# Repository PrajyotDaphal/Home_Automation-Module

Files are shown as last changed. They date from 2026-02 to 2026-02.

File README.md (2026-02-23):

# 🏠 Home Automation Control Module (PCB Based)

## 📌 Project Overview

This project is a **PCB-based Home Automation Control Module** designed to control multiple AC appliances safely using relay isolation. The system uses optocouplers for electrical isolation, transistor drivers for relay switching, and an onboard AC-to-DC power module to power the control circuit.

The module can be controlled using:

* Microcontroller (ESP8266, Arduino, etc.)
* External digital logic
* Smartphone-based IoT system
* Manual control system

This design ensures **safety, reliability, and industrial-level performance**.

---

## ✨ Features

* Control up to **8 AC appliances**
* **Complete electrical isolation** using PC817 optocouplers
* **Onboard AC-DC converter (HLK-10M05)** – no external power supply required
* **Relay driver circuit using BC547 transistors**
* **Flyback diode protection** for relays
* **Status LEDs for each channel**
* **RC snubber for noise protection**
* **Compact and optimized PCB layout**
* Suitable for:

  * Home automation
  * Industrial automation
  * IoT systems
  * Smart switchboards

---

## 🔧 Hardware Components

| Component | Quantity |
| --- | --- |
| HLK-10M05 AC-DC Module | 1 |
| Relay (5V) | 8 |
| PC817 Optocoupler | 8 |
| BC547 Transistor | 8 |
| 1N4007 Diode | 8+ |
| LEDs | 8 |
| Resistors (330Ω, 1kΩ, 220kΩ, etc.) | Multiple |
| Capacitors (Electrolytic and Ceramic) | Multiple |
| Screw Terminals | Multiple |
| Buzzer | 1 |
| MOV (optional safety) | 1 |

---

## ⚡ Power Supply

**Input:**

* 230V AC mains

**Output:**

* 5V DC (from HLK-10M05)

Used to power:

* Optocouplers
* Relay coils
* Logic circuit

---

## 🔌 Pin Configuration

### Input Control Header

| Pin | Function |
| --- | --- |
| IN1 | Relay 1 control |
| IN2 | Relay 2 control |
| IN3 | Relay 3 control |
| IN4 | Relay 4 control |
| IN5 | Relay 5 control |
| IN6 | Relay 6 control |
| IN7 | Relay 7 control |
| IN8 | Relay 8 control |
| VCC | 5V |
| GND | Ground |

---

## 🔄 Working Principle

1. Control signal applied to input pin
2. Optocoupler provides isolation
3. Transistor amplifies signal
4. Relay activates
5. Appliance turns ON/OFF

Isolation ensures protection from high voltage.

---

## 📷 Schematic

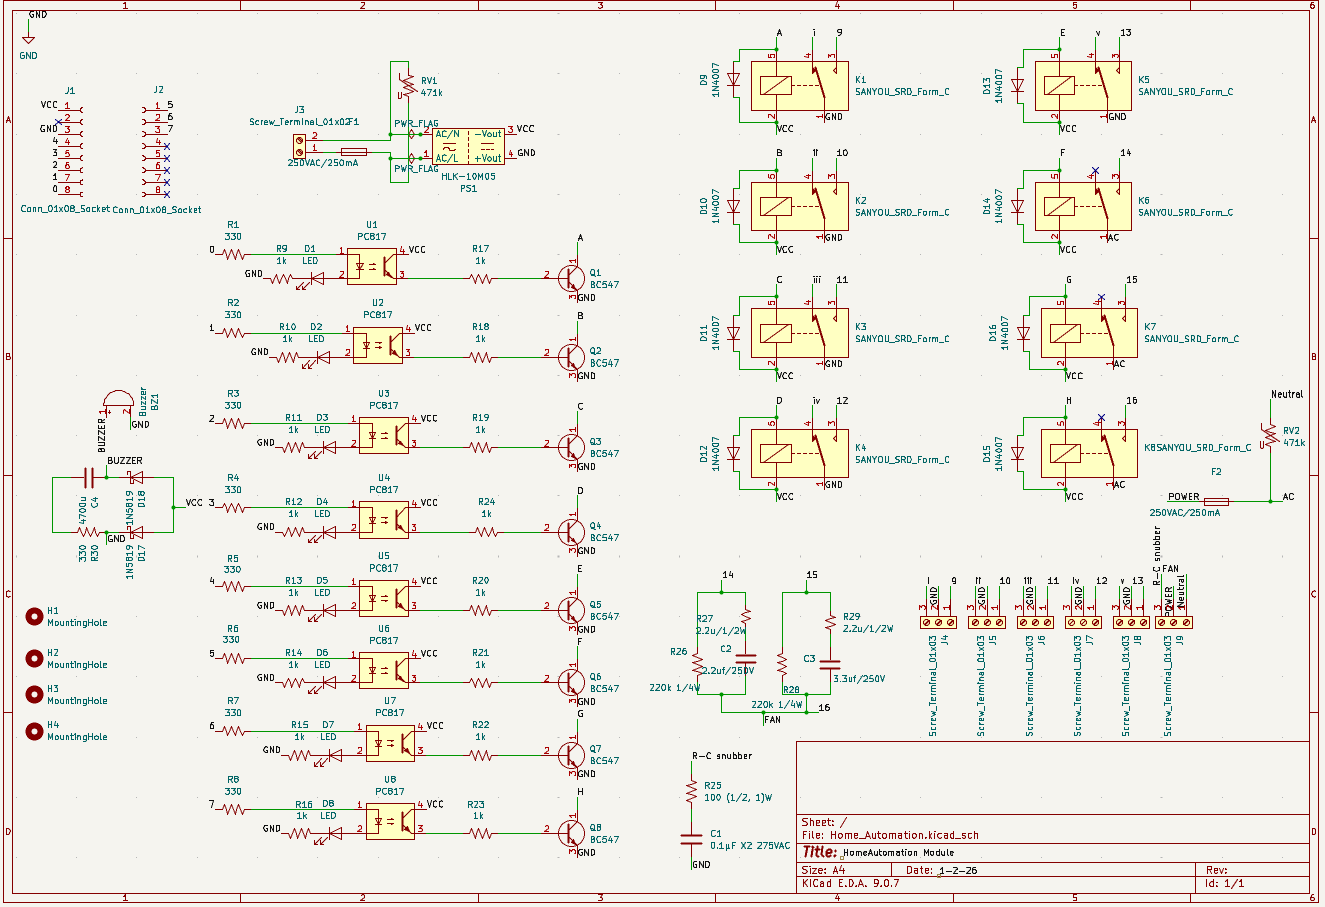
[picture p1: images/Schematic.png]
Schematic


---

## 🧩| Full Layout | Upper Copper |

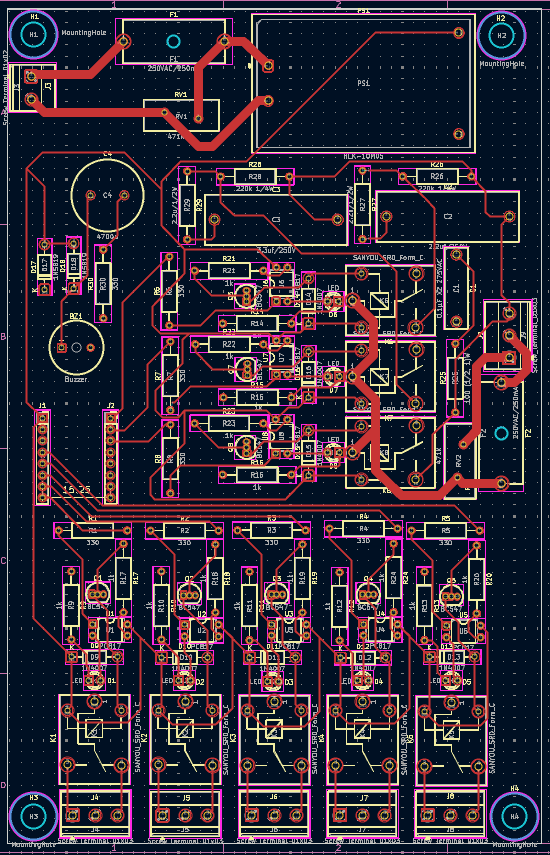
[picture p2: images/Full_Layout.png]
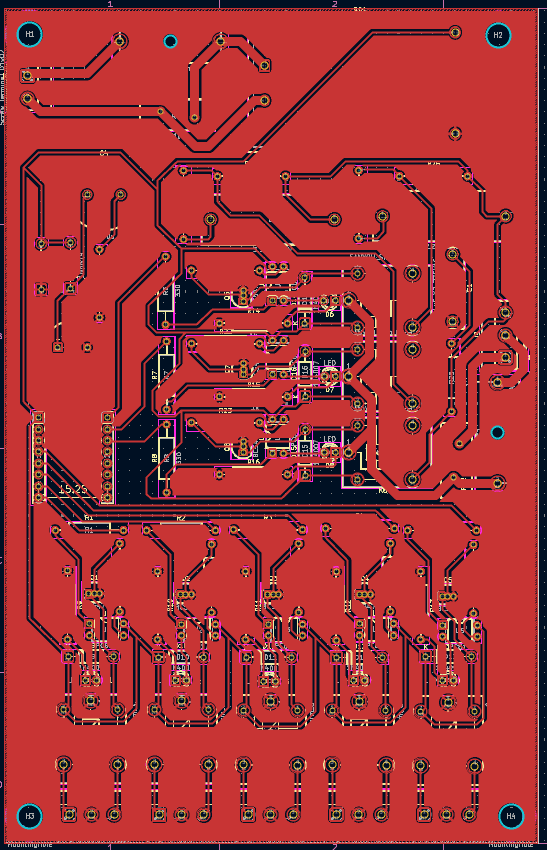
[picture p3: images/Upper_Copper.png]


---

## 🔷 PCB 3D View

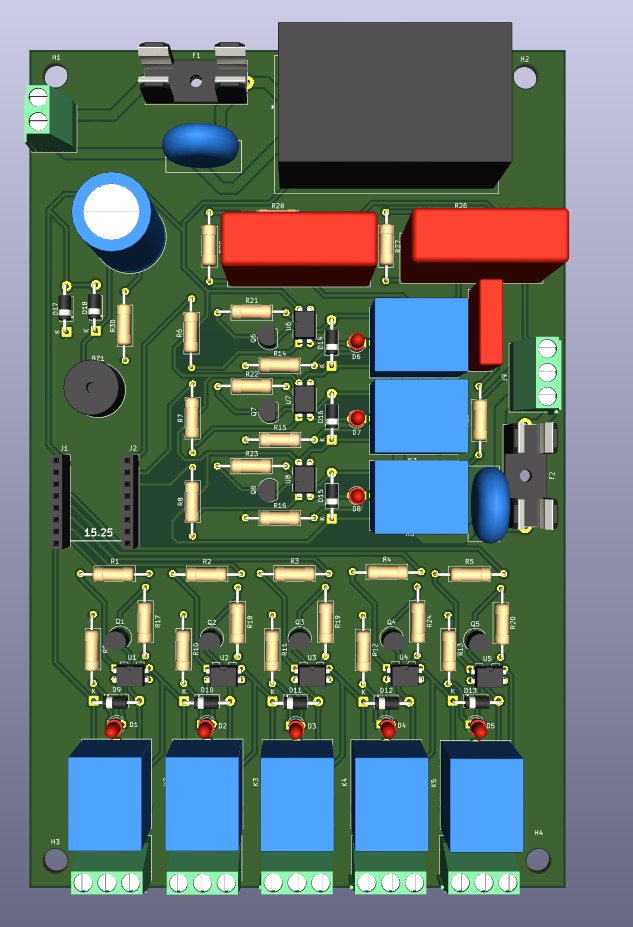
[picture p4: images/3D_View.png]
3D_View


---

## 🛡️ Safety Features

* Optocoupler isolation
* Flyback diode protection
* RC snubber protection
* Proper PCB trace width for AC
* Separate AC and DC sections
* Fuse protection support

---

## 🌐 Applications

* Smart Home Automation
* IoT Control Systems
* Industrial Automation
* Remote Appliance Control
* Smart Switchboard

---

## 🧠 Compatible Controllers

* ESP8266
* ESP32
* Arduino Uno / Nano
* Raspberry Pi
* Any microcontroller with GPIO output

---

## 📁 Project Structure

```
Home-Automation-PCB/
│
├── KiCAD/
│   └── home_automation.kicad_pcb
│   └── home_automation.kicad_sch
│   └── home_automation.kicad_prl
│   └── home_automation.kicad_pro
│   └── home_automation.dsn
│ 
├── images/
│   ├── schematic.png
│   └── pcb_layout.png
|   └── 3D_View.png
|   └── Upper_Copper.png
│
├── gerber/
│   └── production files
|
├── gerber/Drill
│   └── production files
│
└── README.md
```

---

## 🚀 How to Use

1. Connect AC mains input
2. Connect appliances to relay terminals
3. Connect microcontroller to input header
4. Apply control signal
5. Appliance will turn ON/OFF

---

## ⚠️ Warning

This project uses **HIGH VOLTAGE AC**.

* Do not touch while powered
* Use proper insulation
* Use fuse and enclosure
* Only trained persons should handle

---

## 📌 Author

**Project by:** Prajyot Daphal
**Designed using:** KiCad
**Type:** Home Automation PCB Module

---

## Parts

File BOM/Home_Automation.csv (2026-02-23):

Id | Designator | Footprint | Quantity | Designation | Supplier and ref
1 | D2,D3,D7,D4,D8,D1,D6,D5 | LED_D3.0mm | 8 | LED
2 | U5,U3,U2,U6,U7,U8,U1,U4 | DIP-4_W7.62mm | 8 | PC817
3 | J5,J7,J8,J4,J9,J6 | TerminalBlock_Phoenix_MKDS-1,5-3_1x03_P5.00mm_Horizontal | 6 | Screw_Terminal_01x03
4 | D16,D9,D15,D11,D12,D13,D10,D14 | D_DO-41_SOD81_P10.16mm_Horizontal | 8 | 1N4007
5 | R15,R18,R20,R24,R13,R21,R23,R16,R22,R9,R17,R19,R14,R10,R11,R12 | R_Axial_DIN0309_L9.0mm_D3.2mm_P15.24mm_Horizontal | 16 | 1k
6 | R30,R2,R3,R8,R4,R5,R7,R1,R6 | R_Axial_DIN0309_L9.0mm_D3.2mm_P15.24mm_Horizontal | 9 | 330
7 | BZ1 | MagneticBuzzer_ProSignal_ABT-410-RC | 1 | Buzzer
8 | K7,K5,K3,K8,K4,K2,K1,K6 | Relay_SPDT_SANYOU_SRD_Series_Form_C | 8 | SANYOU_SRD_Form_C
9 | Q6,Q1,Q8,Q5,Q2,Q3,Q4,Q7 | TO-92_Inline | 8 | BC547
10 | C2 | C_Rect_L31.5mm_W11.0mm_P27.50mm_MKS4 | 1 | 2.2uf/250V
11 | R25 | R_Axial_DIN0309_L9.0mm_D3.2mm_P15.24mm_Horizontal | 1 | 100 (1/2, 1)W
12 | C4 | C_Radial_D16.0mm_H25.0mm_P7.50mm | 1 | 4700u
13 | R28,R26 | R_Axial_DIN0309_L9.0mm_D3.2mm_P15.24mm_Horizontal | 2 | 220k 1/4W
14 | PS1 | Converter_ACDC_Hi-Link_HLK-10Mxx | 1 | HLK-10M05
15 | F2,F1 | Fuseholder_Cylinder-5x20mm_Schurter_0031_8201_Horizontal_Open | 2 | 250VAC/250mA
16 | D17,D18 | D_DO-41_SOD81_P10.16mm_Horizontal | 2 | 1N5819
17 | J3 | TerminalBlock_Phoenix_MKDS-1,5-2-5.08_1x02_P5.08mm_Horizontal | 1 | Screw_Terminal_01x02
18 | R29,R27 | R_Axial_DIN0309_L9.0mm_D3.2mm_P15.24mm_Horizontal | 2 | 2.2u/1/2W
19 | C1 | C_Rect_L18.0mm_W5.0mm_P15.00mm_FKS3_FKP3 | 1 | 0.1µF X2 275VAC
20 | J1,J2 | PinSocket_1x08_P2.54mm_Vertical | 2 | Conn_01x08_Socket
21 | C3 | C_Rect_L31.5mm_W11.0mm_P27.50mm_MKS4 | 1 | 3.3uf/250V
22 | RV1,RV2 | RV_Disc_D16.5mm_W6.7mm_P7.5mm | 2 | 471k

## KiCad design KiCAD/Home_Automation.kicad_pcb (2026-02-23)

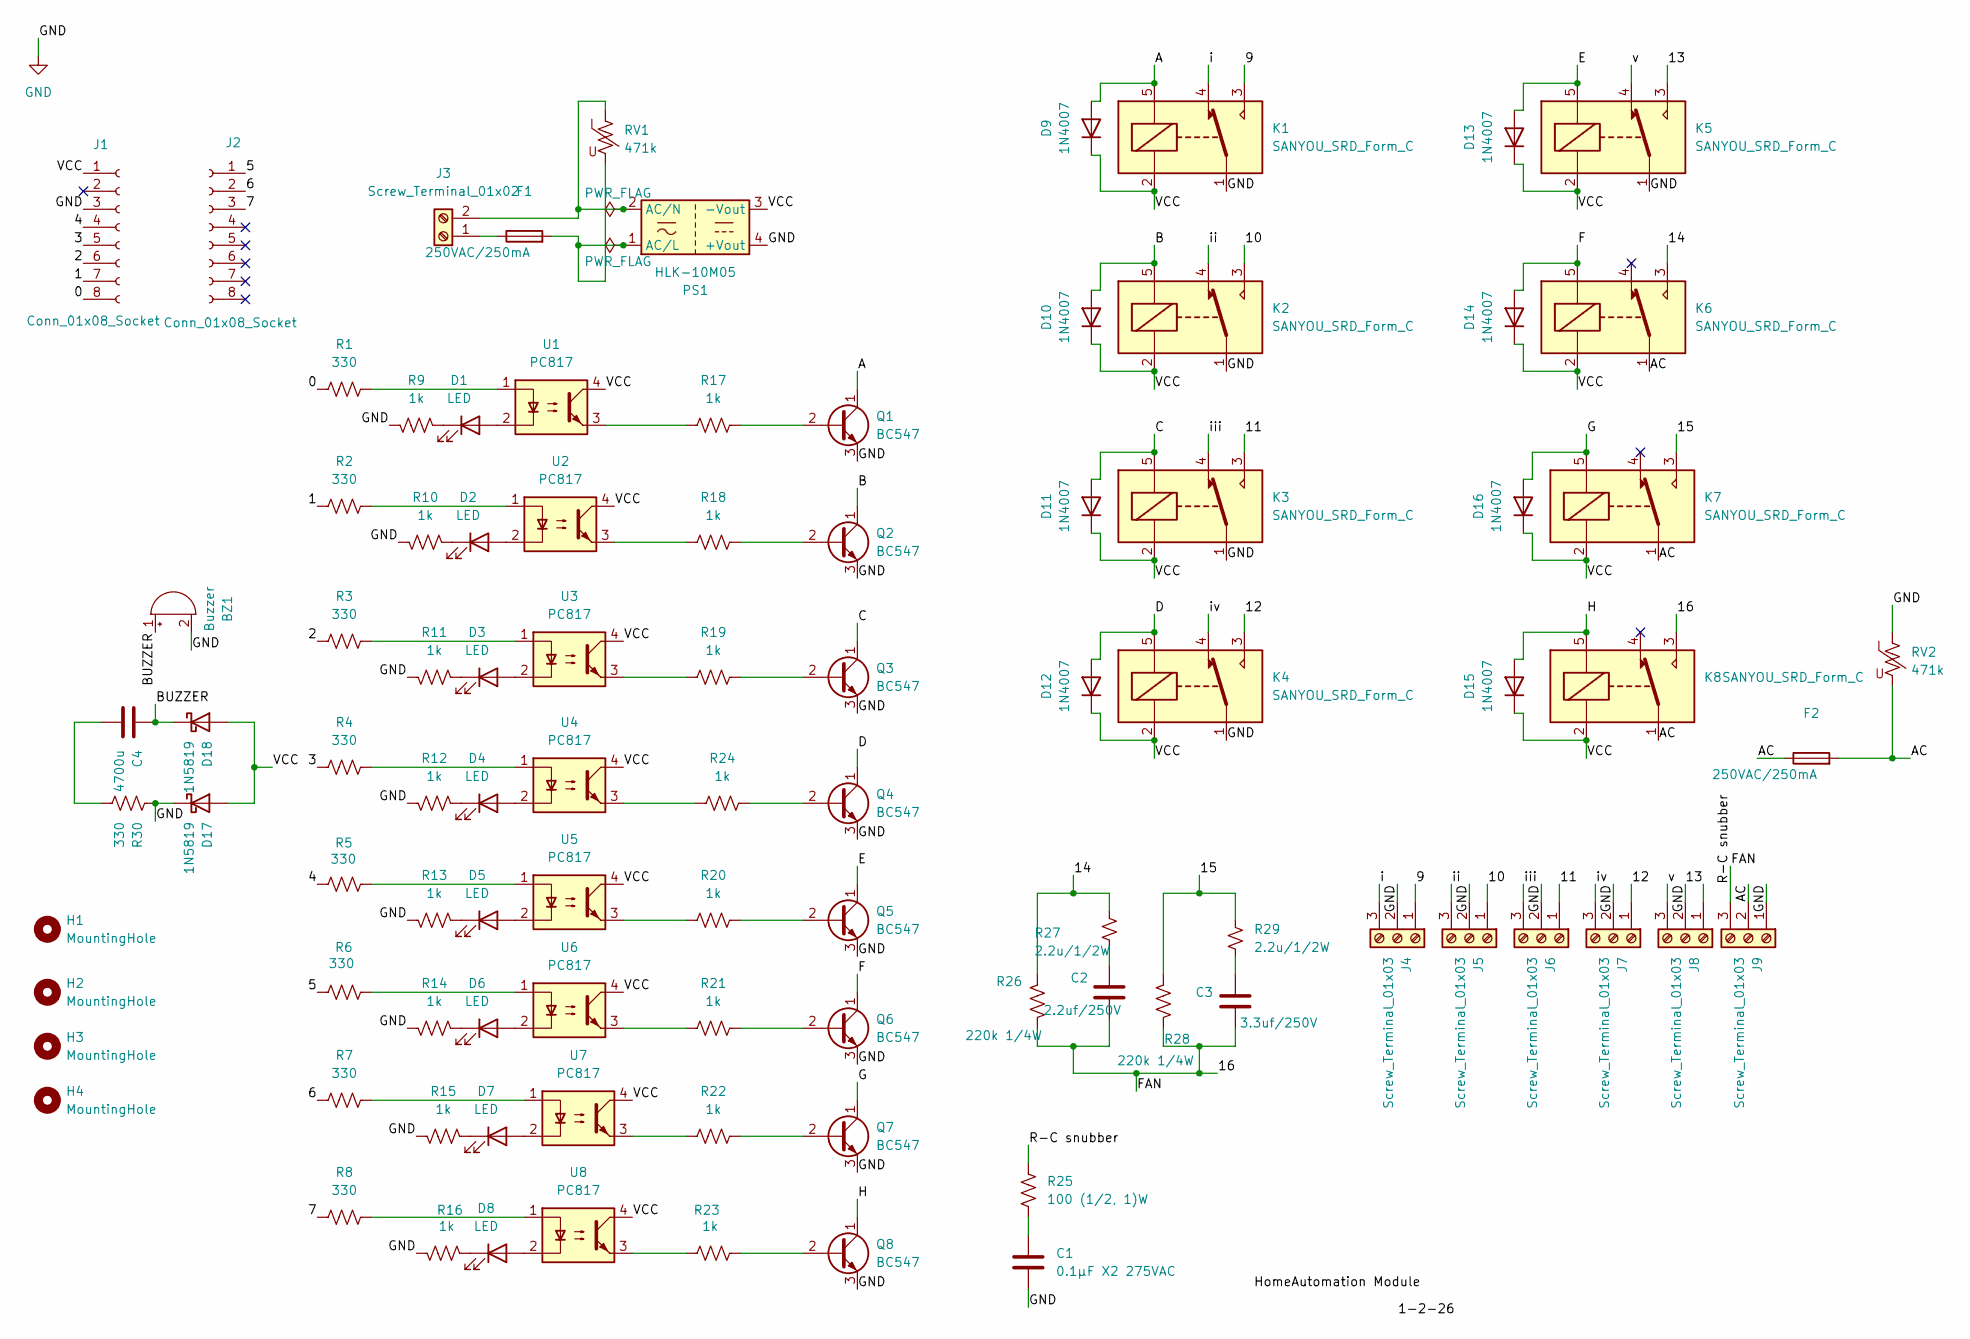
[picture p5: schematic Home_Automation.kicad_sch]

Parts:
BZ1: Buzzer; MagneticBuzzer_ProSignal_ABT-410-RC
C1: 0.1µF X2 275VAC; C_Rect_L18.0mm_W5.0mm_P15.00mm_FKS3_FKP3
C2: 2.2uf/250V; C_Rect_L31.5mm_W11.0mm_P27.50mm_MKS4
C3: 3.3uf/250V; C_Rect_L31.5mm_W11.0mm_P27.50mm_MKS4
C4: 4700u; C_Radial_D16.0mm_H25.0mm_P7.50mm
D1, D2, D3, D4, D5, D6, D7, D8: LED; LED_D3.0mm
D9, D10, D11, D12, D13, D14, D15, D16: 1N4007; D_DO-41_SOD81_P10.16mm_Horizontal
D17, D18: 1N5819; D_DO-41_SOD81_P10.16mm_Horizontal
F1, F2: 250VAC/250mA; Fuseholder_Cylinder-5x20mm_Schurter_0031_8201_Horizontal_Op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
H1, H2, H3, H4: MountingHole; MountingHole_5.3mm_M5
J1, J2: Conn_01x08_Socket; PinSocket_1x08_P2.54mm_Vertical
J3: Screw_Terminal_01x02; TerminalBlock_Phoenix_MKDS-1,5-2-5.08_1x02_P5.08mm_Horizont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
J4, J5, J6, J7, J8, J9: Screw_Terminal_01x03; TerminalBlock_Phoenix_MKDS-1,5-3_1x03_P5.00mm_Horizontal
K1, K2, K3, K4, K5, K6, K7, K8: SANYOU_SRD_Form_C; Relay_SPDT_SANYOU_SRD_Series_Form_C
PS1: HLK-10M05; Converter_ACDC_Hi-Link_HLK-10Mxx
Q1, Q2, Q3, Q4, Q5, Q6, Q7, Q8: BC547; TO-92_Inline
R1, R2, R3, R4, R5, R6, R7, R8, R30: 330; R_Axial_DIN0309_L9.0mm_D3.2mm_P15.24mm_Horizontal
R9, R10, R11, R12, R13, R14, R15, R16, R17, R18, R19, R20, R21, R22, R23, R24: 1k; R_Axial_DIN0309_L9.0mm_D3.2mm_P15.24mm_Horizontal
R25: 100 (1/2, 1)W; R_Axial_DIN0309_L9.0mm_D3.2mm_P15.24mm_Horizontal
R26, R28: 220k 1/4W; R_Axial_DIN0309_L9.0mm_D3.2mm_P15.24mm_Horizontal
R27, R29: 2.2u/1/2W; R_Axial_DIN0309_L9.0mm_D3.2mm_P15.24mm_Horizontal
RV1, RV2: 471k; RV_Disc_D16.5mm_W6.7mm_P7.5mm
U1, U2, U3, U4, U5, U6, U7, U8: PC817; DIP-4_W7.62mm

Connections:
/0: J1.8, R1.2
/1: J1.7, R2.2
/2: J1.6, R3.2
/3: J1.5, R4.2
/4: J1.4, R5.2
/5: J2.1, R6.2
/6: J2.2, R7.2
/7: J2.3, R8.2
/9: J4.1, K1.3
/10: J5.1, K2.3
/11: J6.1, K3.3
/12: J7.1, K4.3
/13: J8.1, K5.3
/14: K6.3, R26.1, R27.1
/15: K7.3, R28.1, R29.1
/16: C2.2, C3.2, J9.3, K8.3, R25.1, R26.2, R28.2
/A: D9.2 (A), K1.5, Q1.1 (C)
/B: D10.2 (A), K2.5, Q2.1 (C)
/BUZZER: BZ1.1 (+), C4.1, D18.1 (K)
/C: D11.2 (A), K3.5, Q3.1 (C)
/D: D12.2 (A), K4.5, Q4.1 (C)
/E: D13.2 (A), K5.5, Q5.1 (C)
/F: D14.2 (A), K6.5, Q6.1 (C)
/G: D16.2 (A), K7.5, Q7.1 (C)
/H: D15.2 (A), K8.5, Q8.1 (C)
/VCC: D9.1 (K), D10.1 (K), D11.1 (K), D12.1 (K), D13.1 (K), D14.1 (K), D15.1 (K), D16.1 (K), D17.2 (A), D18.2 (A), J1.1, K1.2, K2.2, K3.2, K4.2, K5.2, K6.2, K7.2, K8.2, PS1.3 (-Vout), U1.4, U2.4, U3.4, U4.4, U5.4, U6.4, U7.4, U8.4
/i: J4.3, K1.4
/ii: J5.3, K2.4
/iii: J6.3, K3.4
/iv: J7.3, K4.4
/v: J8.3, K5.4
unnamed: C1.1, R25.2
unnamed: C2.1, R27.2
unnamed: C3.1, R29.2
unnamed: C4.2, R30.2
unnamed: D1.2 (A), U1.2
unnamed: D1.1 (K), R9.2
unnamed: D2.2 (A), U2.2
unnamed: D2.1 (K), R10.2
unnamed: D3.2 (A), U3.2
unnamed: D3.1 (K), R11.2
unnamed: D4.2 (A), U4.2
unnamed: D4.1 (K), R12.2
unnamed: D5.2 (A), U5.2
unnamed: D5.1 (K), R13.2
unnamed: D6.2 (A), U6.2
unnamed: D6.1 (K), R14.2
unnamed: D7.2 (A), U7.2
unnamed: D7.1 (K), R15.2
unnamed: D8.2 (A), U8.2
unnamed: D8.1 (K), R16.2
unnamed: F1.1, J3.1
unnamed: J3.2, PS1.2 (AC/N), RV1.1
unnamed: F1.2, PS1.1 (AC/L), RV1.2
unnamed: Q1.2 (B), R17.1
unnamed: Q2.2 (B), R18.1
unnamed: Q3.2 (B), R19.1
unnamed: Q4.2 (B), R24.1
unnamed: Q5.2 (B), R20.1
unnamed: Q6.2 (B), R21.1
unnamed: Q7.2 (B), R22.1
unnamed: Q8.2 (B), R23.1
unnamed: R1.1, U1.1
unnamed: R2.1, U2.1
unnamed: R3.1, U3.1
unnamed: R4.1, U4.1
unnamed: R5.1, U5.1
unnamed: R6.1, U6.1
unnamed: R7.1, U7.1
unnamed: R8.1, U8.1
unnamed: R17.2, U1.3
unnamed: R18.2, U2.3
unnamed: R19.2, U3.3
unnamed: R20.2, U5.3
unnamed: R21.2, U6.3
unnamed: R22.2, U7.3
unnamed: R23.2, U8.3
unnamed: R24.2, U4.3

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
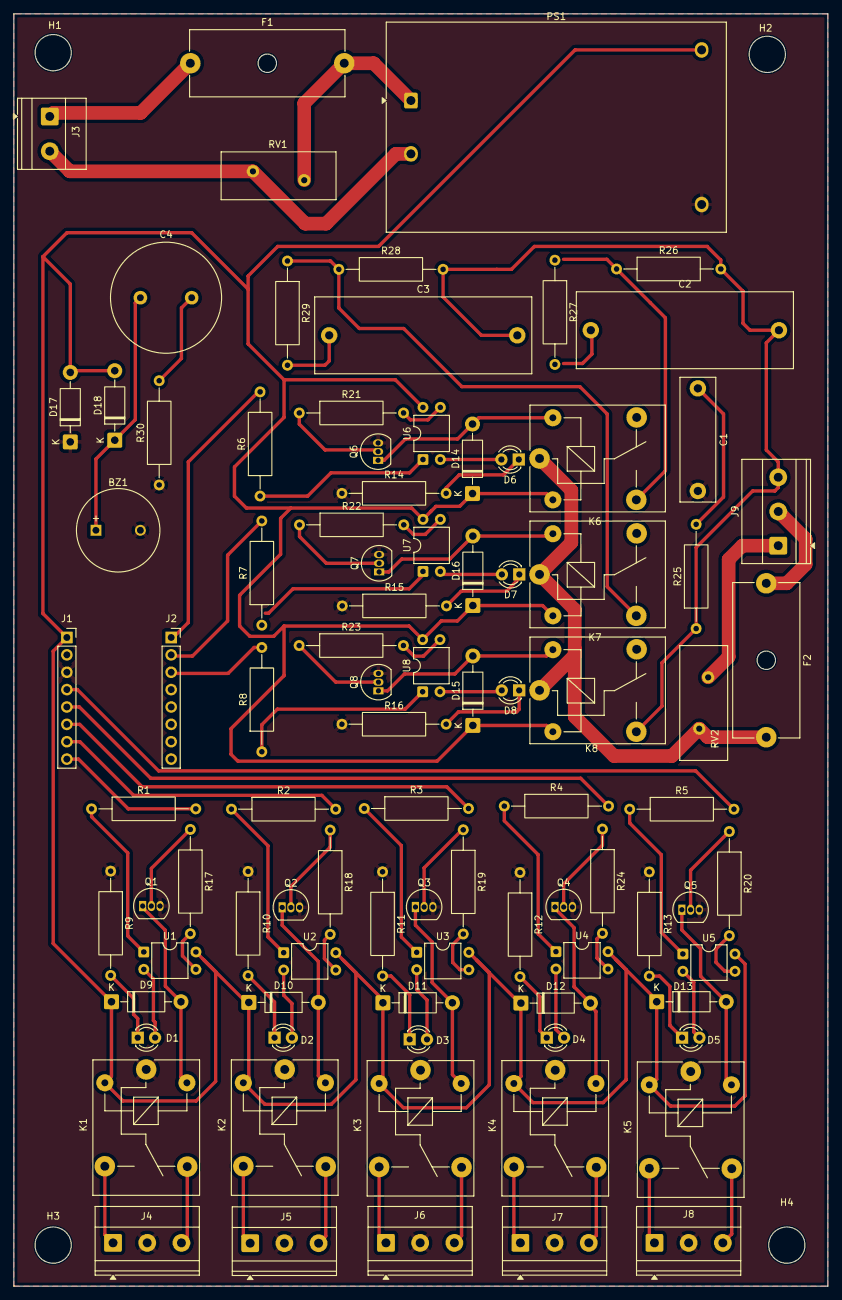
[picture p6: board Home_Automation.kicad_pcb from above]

Board: 2 copper layers, 119.0 x 186.0 mm, 95 parts (0 on the bottom side), 82 nets.
